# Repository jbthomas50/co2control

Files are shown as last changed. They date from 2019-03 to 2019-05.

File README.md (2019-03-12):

# co2control
**co2 control system**
 
This system controls a solenoid attached to a co2 tank. There is a sensor in the system that tells the arduino the concentration of co2 in the system, and then the solenoid can open and close to get thee correct concentration of co2. The concentration of co2 is set by the user using two potentiometers. 
There will also be fans within the system to create circulation. 
There is an LCD screen to display the co2 concentration setting and the current concentration.

*Suggestions*

The LiquidCrystal.h library for the arduino isn't good. Go to 
the following website to download a better version, rename it, and replace 
it with the current arduino LiguidCrystal.h library.
https://bitbucket.org/fmalpartida/new-liquidcrystal/downloads/?tab=downloads

To use the ESP 8266 wifi module, follow the instructions located 
at this website:

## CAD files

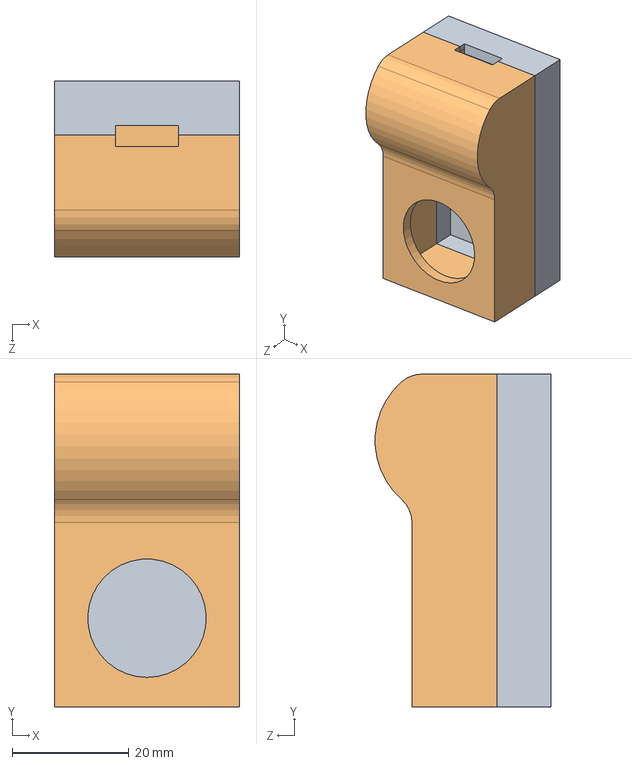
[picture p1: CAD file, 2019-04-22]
3D_Models/sensorCaseAssem.SLDASM
31.8 x 57.1 x 30.1 mm
sensorCaseBack
sensorCaseFront

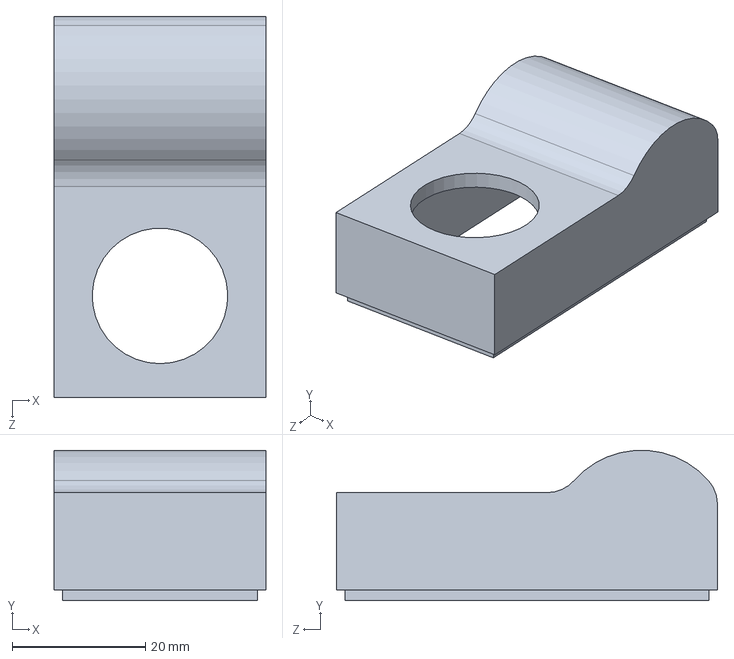
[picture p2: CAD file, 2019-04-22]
3D_Models/sensorCaseFront.SLDPRT
31.8 x 22.5 x 57.1 mm

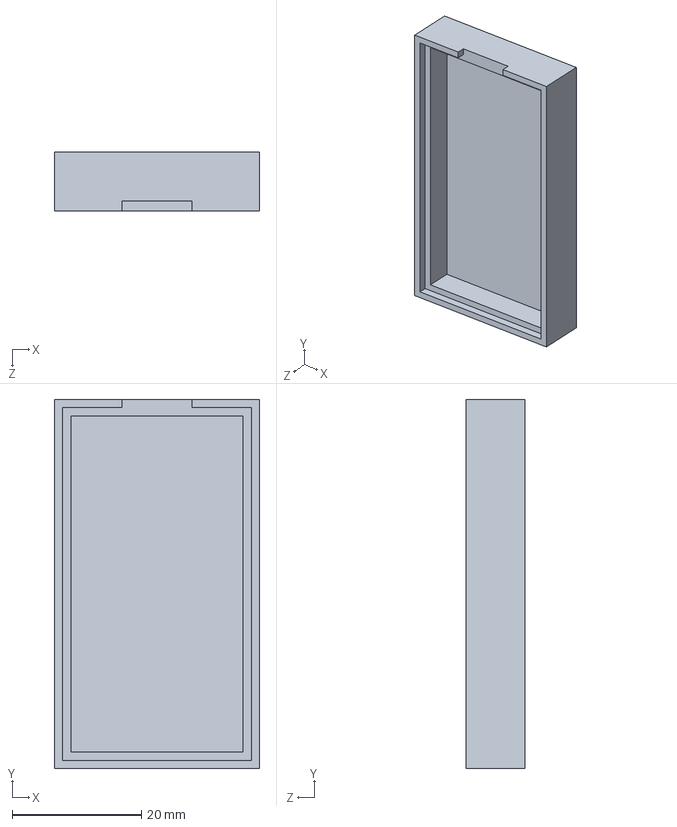
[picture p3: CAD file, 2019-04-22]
3D_Models/sensorCaseBack.SLDPRT
31.8 x 57.1 x 9.21 mm

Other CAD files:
3D_Models/sensorCaseBack.STL
3D_Models/sensorCaseFront.STL

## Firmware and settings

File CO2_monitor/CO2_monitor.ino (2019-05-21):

/******************************************************************
 * CO2 control project
 * 
 * Features:
 *    Co2 sensor
 *    User set desired co2 level
 *    Autonomously controlled solenoid
 *    Four fans to mix air
 *    User set number of fans running
 *    Two lcd screens to display information
 *    Button to turn on/off screen backlights
 *    Write to SD card and google docs
 *    
 * Written by:
 *    Zac Carico and James Thomas
 *****************************************************************/

 /*
  * Possible scheduler: protothread library
  */

/******************************************************************
 *  Arduino Setup:
 *    Digital Pins:
 *      Wifi:                   0(Rx), 1(Tx)
 *      Fans:                   2, 3, 4, 5 
 *      Solenoid:               7
 *      CO2 sensor:             12(Rx), 13(Tx)
 *      **Free:                 6, 8, 9, 10, 11
 * 
 *    Analog Pins:
 *      Fan Pot:                0 
 *      CO2 Pots:               1, 2
 *      I2c:                    4(SDA), 5(SCL) // SD card, 2 screens
 *      **Free:                 3
 *****************************************************************/

//Arduino Libraries
#include <Arduino_FreeRTOS.h>
//#include <semphr.h>
#include <LiquidCrystal_I2C.h>
#include <SoftwareSerial.h>

//Project Libraries
#include "fan.h"
#include "CO2_Sensor.h"

//SEMAPHORES
//SemaphoreHandle_t xLevelMutex;
//SemaphoreHandle_t xTargetMutex;
// QueueHandle_t xDisplayQueue;

//GLOBAL VARIABLES
volatile unsigned long CO2_target = 100;
volatile unsigned long CO2_level = 100;
LiquidCrystal_I2C lcd2(0x27,2,1,0,4,5,6,7);
LiquidCrystal_I2C lcd1(0x20,2,1,0,4,5,6,7);
SoftwareSerial sensorSerial(12, 13);        // RX, TX pins on Ardunio
CO2_Sensor mySensor(&sensorSerial);         // Set up sensor with software serial object.
uint8_t numFans = 0;
Fans fans = Fans(2, 3, 4, 5);
bool refreshDisplay = true;
uint8_t solenoidPin = 7;

//Prototypes
//void writeToCloud(void *pvParameters);
void readCO2_sensor(void *pvParameters);
void manageCO2_levels(void *pvParameters);
void setUpHardware();

void setup() 
{
  Serial.begin(9600);
  setUpHardware();

  //define Semaphores
//  if(xLevelMutex == NULL)
//  {
//    xLevelMutex = xSemaphoreCreateMutex();
//    if( (xLevelMutex) != NULL)
//    {
//      xSemaphoreGive((xLevelMutex));
//    }
//  }
//
//  if(xTargetMutex == NULL)
//  {
//    xTargetMutex = xSemaphoreCreateMutex();
//    if( (xTargetMutex) != NULL)
//    {
//      xSemaphoreGive((xTargetMutex));
//    }
//  }

  xTaskCreate(manageCO2_levels, "mngCO2", 
              100, NULL, 3, NULL);
  xTaskCreate(readCO2_sensor, "rdCO2", 
              100, NULL, 3, NULL);
//   xTaskCreate(writeToCloud, "wrt2cld", 
//               100, NULL, 1, NULL);
}

void loop() 
{
  //Tasks during down time, or delays.
  uint8_t tempFans = numFans;
  numFans = map(analogRead(A0), 0, 1024, 0, 5);

  if (numFans != tempFans)
  {
    fans.on(numFans);
    refreshDisplay = true;
  }
  if(refreshDisplay)
  {
    // Reset screen
    lcd2.setCursor(4, 0);
    lcd2.print("          ");
    lcd2.setCursor(4, 1);
    lcd2.print("          ");

    lcd2.setCursor(4, 0);
    lcd2.print(CO2_level);
  
    lcd2.setCursor(4, 1);
    lcd2.print(CO2_target);
  
    lcd1.setCursor(6, 1);
    lcd1.print(numFans);

    refreshDisplay = false;
  }
}

void setUpHardware()
{
  // LCD 1 (left side)
  lcd1.begin(16,2);
  lcd1.clear();
  lcd1.home();
  
  lcd1.print("Control Station");
  lcd1.setCursor(0, 1);
  lcd1.print(F("FANS: "));
  
  // LCD 2 (right side)
  lcd2.begin(16,2);
  lcd2.clear();
  lcd2.home();
  
  lcd2.print(F("ACT: "));
  lcd2.setCursor(0,1);
  lcd2.print(F("SET: "));

  pinMode(A0, INPUT);                   // fan control (left)
  pinMode(A1, INPUT);                   // CO2 1 million (middle)
  pinMode(A2, INPUT);                   // CO2 10 thousand (right)
  pinMode(solenoidPin, OUTPUT);
}

/**
 * Writes information to the cloud (Should make this a time interupt)
 */
//void writeToCloud(void *pvParameters)
//{  
//  //runs when function is called for the first time.
//
//  //runs forever
//  for(;;)
//  {
//    //TODO: Write to cloud here... 
//  }
////  Serial.println("written to cloud");
//}

/**
 * Reads CO2 sensor
 */
void readCO2_sensor(void *pvParameters)
{
  //runs when function is called for the first time.
  unsigned long tempLevel = 0;
  unsigned long tempTarget = 0;
  //runs forever
  for(;;)
  {
    // Read sensor here...
    mySensor.read();
    tempLevel = mySensor.getCO2();

    // READ USER INPUT
    tempTarget = (map(analogRead(A2), 0, 1023, 0, 100) * 100) + 
                 (map(analogRead(A1), 0, 1023, 1, 100) * 10000);
    if (tempTarget > 1000000)
    {
      tempTarget = 1000000;
    }
    
//    if(xSemaphoreTake(xLevelMutex, 1000))
//    {
      if(CO2_level != tempLevel)
        refreshDisplay = true;
        
      CO2_level = tempLevel;
//      xSemaphoreGive(xLevelMutex);
//    }
//    if(xSemaphoreTake(xTargetMutex, 1000))
//    {
      if(CO2_target != tempTarget)
        refreshDisplay = true;
        
      CO2_target = tempTarget;
//      xSemaphoreGive(xTargetMutex);
//    }

    vTaskDelay(1000/*in ms*/ / portTICK_PERIOD_MS);
  }
}

/**
 * Controls how much CO2 is in the tank, and tries to 
 * match it based on the CO2 Sensor reading
 */
void manageCO2_levels(void *pvParameters)
{
  //runs forever.
  for(;;)
  {
    //TODO: Turn on solenoid here...
    if (CO2_target <= CO2_level)
    {
      digitalWrite(solenoidPin, LOW);
    }
    else
    {
      digitalWrite(solenoidPin, HIGH);
    }
    vTaskDelay(1000/*in ms*/ / portTICK_PERIOD_MS);
  }
}

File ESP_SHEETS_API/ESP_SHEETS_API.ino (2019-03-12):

#include "ESP8266WiFi.h"
#include <SoftwareSerial.h>

//3rd Party website information
const char WEBSITE[] = "api.pushingbox.com"; //pushingbox API server
const String devid = "v9CE1BCE48848641"; //device ID from Pushingbox 

//WiFi information
const char* MY_SSID = "";
const char* MY_PWD =  "";

//Variables to upload to googleSheets
String sheetID = "1cMlEN7ZF2fPk9kcJsDMf5f1v9CnJC_4UUIQ47ErUbcE"; //Google Sheets SheetID
String timestamp;
String setCO2;
String readCO2;

//Serially communicate with arduino
SoftwareSerial arduino(1, 2);

void setup()
{
  connectWiFi();
  String temp;
  if(arduino.available())
  {
//    parseData(String(arduino.read()));
//    int count = 0;
//    while(WiFi.status() != WL_CONNECTED)
//    {
//      connectWiFi();
//      count++;
//      if (count >= 1000)
//        exit;
//    }
    timestamp = String(arduino.read());
    setCO2 = "10";
    readCO2 = "20";
    uploadData();
  }
  else
  {
    timestamp = "30";
    setCO2 = "10";
    readCO2 = "20";
    uploadData();
  }
}

void loop()
{
  
}

void parseData(String data)
{
  int switcher = 0;
  for(int i = 0; i < data.length(); i++)
  {
    if(data[i] == '{')
    {
      i++;
      while(data[i] != '}')
      {
        switch(switcher)
        {
          case 0:
            timestamp += data[i];
        }
        
        i++;
      }
      switcher++;
      if(switcher == 3)
      {
        switcher = 0;
      }
    }
  }
}

void uploadData()
{
  //Print to Serial monitor or Terminal of your chocice at 115200 Baud
  Serial.print("Google Sheets ID: ");
  Serial.println(sheetID);
  Serial.print("Timestamp: ");
  Serial.println(timestamp);
  Serial.print("setCO2: ");
  Serial.print(setCO2);
  Serial.println("PPM");
  Serial.print("CO2 Reading: ");
  Serial.print(readCO2);
  Serial.println("PPM");
    
  WiFiClient client;  //Instantiate WiFi object

    //Start or API service using our WiFi Client through PushingBox
    if (client.connect(WEBSITE, 80))
    { 
        // Variables set to "N/A" are space savers to make
        //   it easier to add more variables in the future
        client.print("GET /pushingbox?devid=" + devid
                     + "&sheetID="      + (String) sheetID
                     + "&timestamp="    + (String) timestamp
                     + "&setCO2="       + (String) setCO2
                     + "&readCO2="      + (String) readCO2
                     + "&var1="         + "N/A"
                     + "&var2="         + "N/A"
                     + "&var3="         + "N/A");

        client.println(" HTTP/1.1");
        client.print("Host: ");
        client.println(WEBSITE);
        client.println("User-Agent: ESP8266/1.0");
        client.println("Connection: close");
        client.println();
        Serial.print("Success!");
    }
    else
    {
      Serial.println("ERROR: Can't connect!");
    }
}

void connectWiFi()
{
  
  Serial.begin(115200);
  Serial.print("Connecting to " + *MY_SSID);
  WiFi.begin(MY_SSID, MY_PWD);
  Serial.println("going into wl connect");

  while (WiFi.status() != WL_CONNECTED) //not connected,..waiting to connect
  {
      delay(1000);
      Serial.print(".");
  }
  Serial.println("wl connected");
  Serial.println("");
  Serial.println("Credentials accepted! Connected to wifi\n ");
  Serial.println("");
}

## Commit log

2018-12-19 added sample code used for the sensor
2018-12-20 Added a CO2 Sensor class, incorporating the code to read from the CO2 sensor
2018-12-20 added functionality to Fan class
2018-12-20 added i2c liquid crystal display library
2018-12-21 got rid of pin 2 initializing
2018-12-22 played with the code. Too much memorygit pull!
    [CO2_monitor.ino]
2019-01-19 Made fan.h lighter weight, added Semaphores, got LCD screen working
2019-01-19 fixed merge conflict in fan.h
2019-02-02 changed some sensor code
2019-03-12 Added some functionality to the CO2_Sensor class. The input from the sensor is now formatted and saved in the co2 variable.
2019-03-12 Added SOLIDWORKS files of case for CO2 sensor
    [sensoCaseAssem.SLDASM, sensorCaseBack.SLDPRT, sensorCaseFront.SLDPRT]
2019-03-12 added a couple of pins and slightly modified some spacing
2019-03-12 removed solenoid class, fixed some bugs
2019-03-12 deleted solenoid include from monitor file
2019-03-12 organized some files
    [sensorCaseAssem.SLDASM, sensorCaseBack.SLDPRT, sensorCaseFront.SLDPRT]
2019-03-12 took the trash out
    [sensoCaseAssem.SLDASM, sensorCaseBack.SLDPRT, sensorCaseFront.SLDPRT]
2019-03-12 Added .STL files
    [sensorCaseBack.STL, sensorCaseFront.STL]
2019-03-21 added software serial code for sensor
2019-04-03 Error in calculating the size of the sensor. Changed dimenstions to fit
    [sensorCaseAssem.SLDASM, sensorCaseBack.SLDPRT, sensorCaseBack.STL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]
2019-04-04 changed sensor code to calibrate
2019-04-09 Changed a few dimensions to better fit CO2 sensor
    [sensorCaseAssem.SLDASM, sensorCaseBack.SLDPRT, sensorCaseBack.STL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]
2019-04-22 added button interrupt for screen backlights
2019-05-11 removed interrupt, prints, and display mutex from read sensor function
2019-05-11 changed fan pins
2019-05-11 fixed bug in saving to SD card
    [CO2_monitor.ino]
2019-05-11 commented some prints out
2019-05-21 made slight changes to CO2 sensor
2019-05-21 testing the sensor
